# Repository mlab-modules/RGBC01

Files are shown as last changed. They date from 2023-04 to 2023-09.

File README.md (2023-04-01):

<!--- PrjInfo ---> <!--- Please remove this line after manually editing --->
<!--- 00a56be08b96043df9e37d6aff7b6990 --->
<!--- Created:2019-02-18 14:37:02.434774: ---> 
<!--- Author:: ---> 
<!--- AuthorEmail:: ---> 
<!--- Tags:: ---> 
<!--- Ust:: ---> 
<!--- Label --->
<!--- ELabel ---> 
<!--- Name:RGBC01A: --->
# RGBC01A
<!--- LongName --->
## I2C sensor colored light
<!--- ELongName ---> 

<!--- Lead --->
The sensor comprises a sensor red, green, blue and clear colors. Communication takes place via the I2C interface. Circuit includes a power supply for external IR LED. The sensor can be used to measure lighting conditions, or also for detection of the line for the bar and the robot for sensing rotation of automotive wheels.
<!--- ELead ---> 

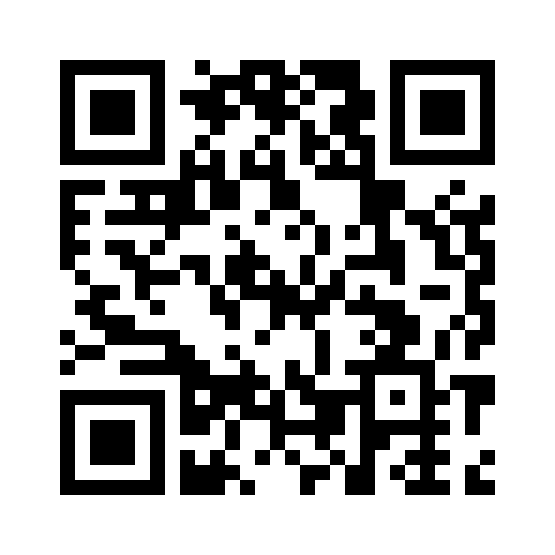
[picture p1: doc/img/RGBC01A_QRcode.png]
RGBC01A
 

<!--- Description --->
<!--- EDescription --->
<!--- Content --->
<!--- EContent --->
<sub><sup> Generated with [MLABweb](https://github.com/MLAB-project/MLABweb). (2019-02-18)</sup></sub>

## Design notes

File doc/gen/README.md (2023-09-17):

# PCB

Board size: 40.13x9.65 mm (1.58x0.38 inches)

- This is the size of the rectangle that contains the board
- Thickness: 1.6 mm (63 mils)
- Material: FR4
- Finish: HAL
- Layers: 2
- Copper thickness: 35 µm

Solder mask: TOP / BOTTOM

- Color: Green

Silk screen: TOP / BOTTOM

- Color: White

# Important sizes

Clearance: 0.2 mm (8 mils)

Track width: 0.4 mm (16 mils)

- By design rules: 0.2 mm (8 mils)

Drill: 0.5 mm (20 mils)

- Vias: 0.5 mm (20 mils) [Design: 0.4 mm (16 mils)]
- Pads: 0.85 mm (33 mils)
- The above values are real drill sizes, they add 0.1 mm (4 mils) to plated holes (PTH)

Via: 0.6/0.4 mm (24/16 mils)

- By design rules: 0.4/0.3 mm (16/12 mils)
- Micro via: yes [0.2/0.1 mm (8/4 mils)]
- Buried/blind via: yes
- Total: 9 (thru: 9 buried/blind: 0 micro: 0)

Outer Annular Ring: 0.05 mm (2 mils)

- By design rules: 0.08 mm (3 mils)

Eurocircuits class: 10B
- Using min drill 0.5 mm for an OAR of 0.05 mm

# General stats

Components count: (SMD/THT)

- Top: 0/7 (THT)
- Bottom: 9/3 (SMD + THT)

Defined tracks:

- 0.2 mm (8 mils)
- 0.3 mm (12 mils)
- 0.4 mm (16 mils)

Used tracks:

- 0.4 mm (16 mils) (90) defined: yes

Defined vias:

Used vias:

- 0.6/0.4 mm (24/16 mils) (Count: 9, Aspect: 2.7 A) defined: no

Holes (excluding vias):

- 0.76 mm (30 mils) (3)
- 0.89 mm (35 mils) (10)
- 3.0 mm (118 mils) (2)

Oval holes:

Drill tools (including vias and computing adjusts and rounding):

- 0.5 mm (20 mils) (9)
- 0.85 mm (33 mils) (3)
- 1.0 mm (39 mils) (10)
- 3.1 mm (122 mils) (2)

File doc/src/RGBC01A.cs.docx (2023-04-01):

I2C snímač barevného světla

Jan Chroust

## Čidlo obsahuje snímač červené, zelené, modré a jasné (clear) barvy. Komunikace probíhá přes I2C rozhraní. Obvod obsahuje i napájení pro externí IR LED. Senzor je možné využít pro měření světelných podmínek, nebo také pro detekci čáry pro čárového robota i pro snímání otáčení pohonných kol.

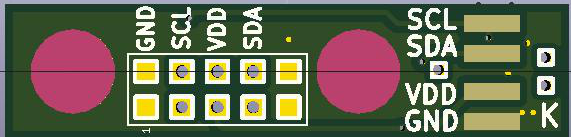
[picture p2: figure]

# 1. Technické parametry

Parametr | Hodnota | Poznámka
Napájecí napětí | 3,3 V
Rozhraní | I2C
I2C adresa | 0x29
Rozměry | 10.13 x 40.13 x 16 mm | Výška nad základní deskou

# 2. Popis konstrukce

Na plošném spoji jsou připraveny vývody pro připojení externí IR LED, pro případ, kdy by nestačila SMD LED umístěna na plošném spoji.

V případě potřeby je možné využít pinu INT, který není na plošném spoji onačen. Je umístěn mezi nápisy SDA a VDD.

Modul byl koncipován tak, že v případě potřeby miniaturizace rozměrů modulu je možné odstřižení plošného spoje hned za prokovem u nápisu GND. Tímto odstřižením se přichází o hřebínek a ochrannou diodu D1.

Adresa modulu je 0x29.

## 2.1. Mechanická konstrukce

Modul obsahuje úchytné šroubky ve všech rozích v rozteči MLAB (10.16mm).

# 3. Osazení a oživení

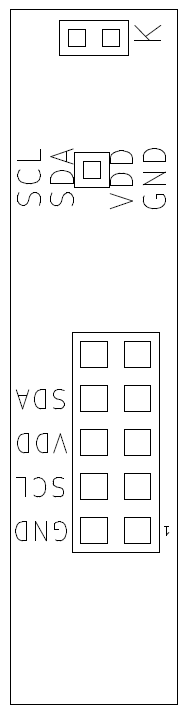
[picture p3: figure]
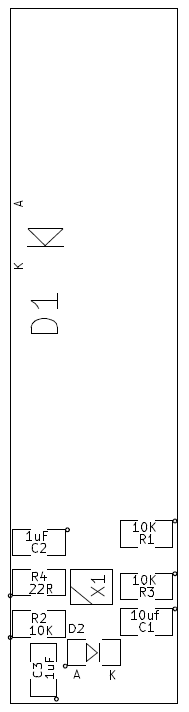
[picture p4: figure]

## 3.1. Osazení

Označení | Typ | Pouzdro | Počet
J3 | CONN1_2 | Straight_2x01 | 1
M1,M2 | HOLE | MountingHole_3mm | 2
X1 | TCS37717 | FN | 1
J1 | JUMP_5X2 | Straight_2x05 | 1
C1 | 10uf | SMD-0805 | 1
C2,C3 | 1uF | SMD-0805 | 2
R1,R3,R2 | 10K | SMD-0805 | 3
R4 | 22R | SMD-0805 | 1
D1 | BZV55C-3,6V | Diode-MiniMELF_Standard | 1
J2 | CONN1_1 | Straight_1x01 | 1
J4,J5,J6,J7 | CONN1_1 | SMD_1x1 | 4
D2 | LL-S170IRC-2A | LED_0805 | 1

RGBC01A / 2016-03-09 / jacho/ http://www.mlab.cz 3 / 3

RGBC01A MLAB

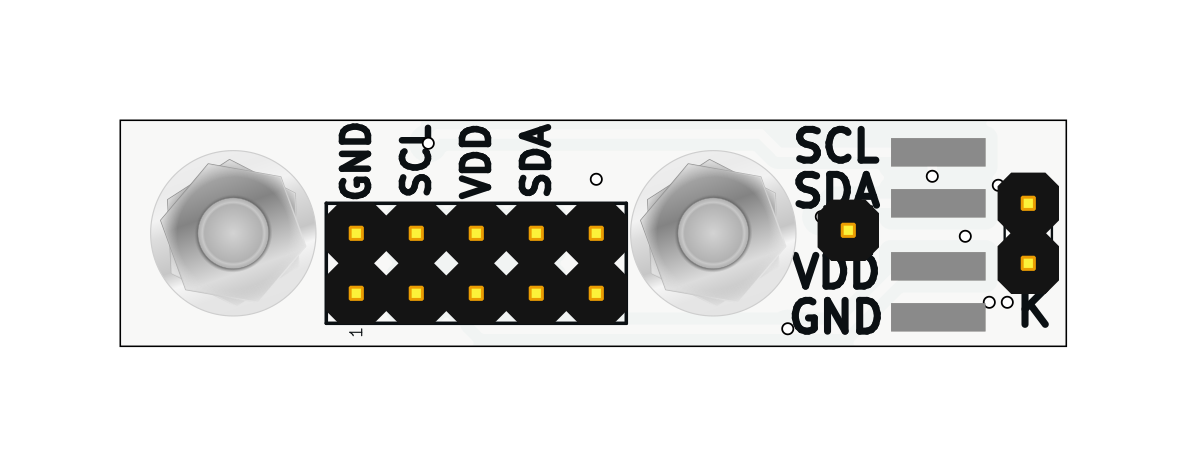
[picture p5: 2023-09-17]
doc/gen/img/RGBC01-top.png

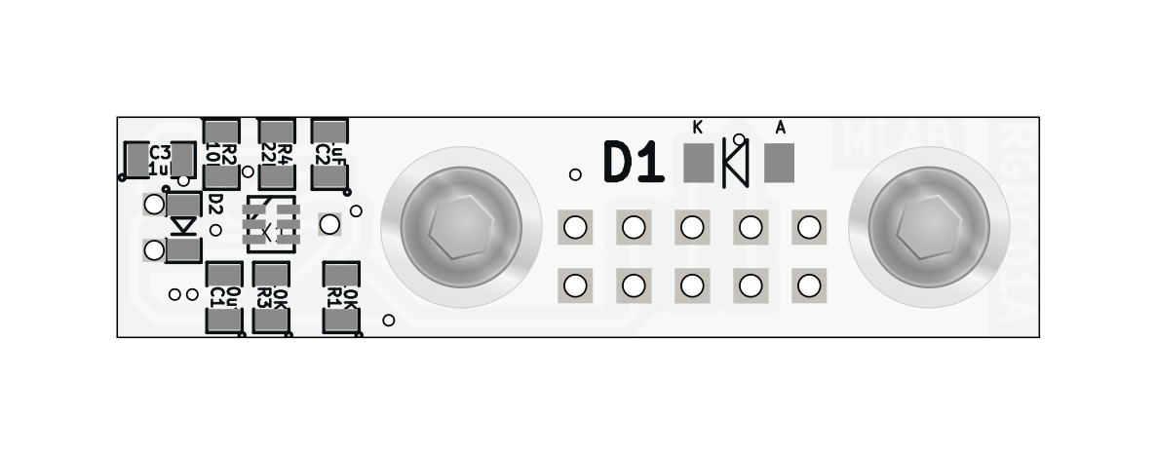
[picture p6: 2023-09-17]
doc/gen/img/RGBC01-bottom.png

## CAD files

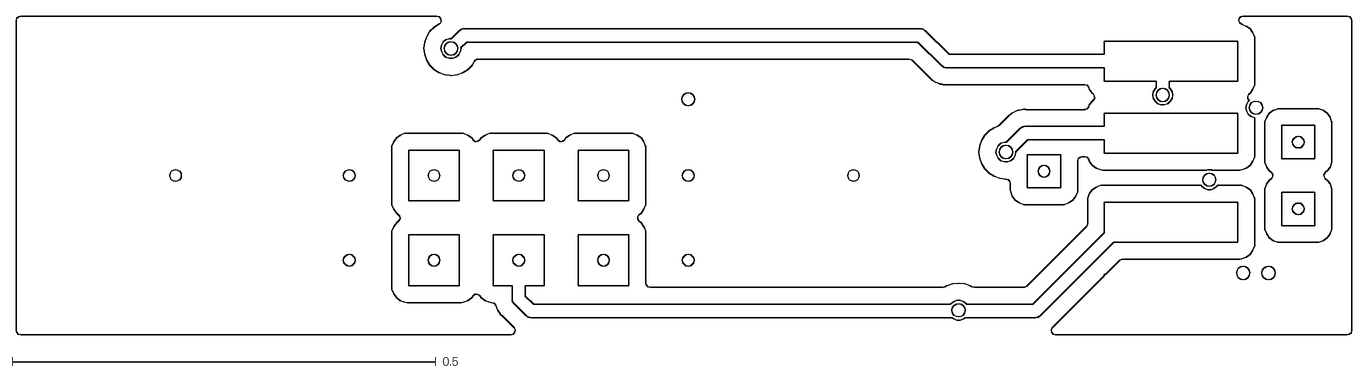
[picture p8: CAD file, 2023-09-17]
doc/gen/dxf/RGBC01-F_Cu.dxf
1.58 x 0.376

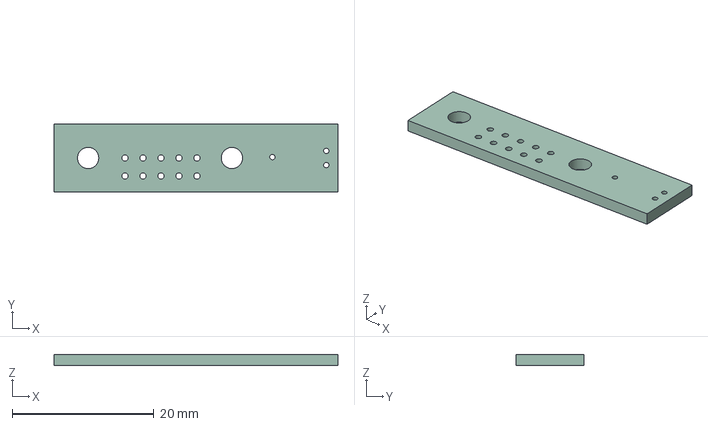
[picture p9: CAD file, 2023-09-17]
doc/gen/RGBC01.step
40.1 x 9.65 x 1.60 mm

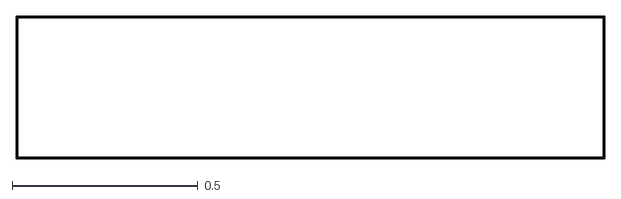
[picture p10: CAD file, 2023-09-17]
doc/gen/dxf/RGBC01-Edge_Cuts.dxf
1.58 x 0.384

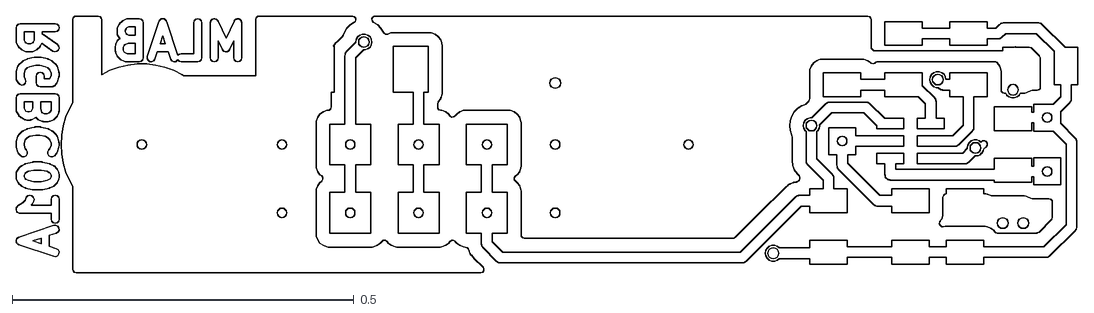
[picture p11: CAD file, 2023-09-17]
doc/gen/dxf/RGBC01-B_Cu.dxf
1.55 x 0.376

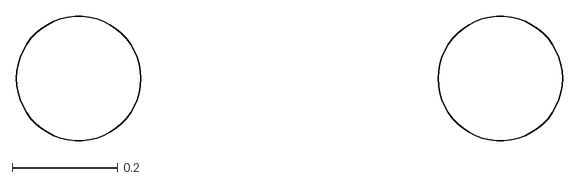
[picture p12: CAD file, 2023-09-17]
doc/gen/dxf/RGBC01-F_Adhesive.dxf
1.04 x 0.236

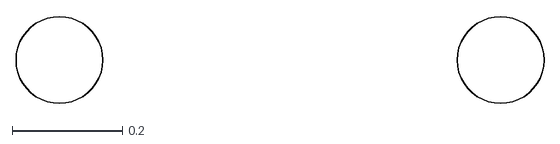
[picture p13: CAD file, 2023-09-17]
doc/gen/dxf/RGBC01-User_Comments.dxf
0.957 x 0.157

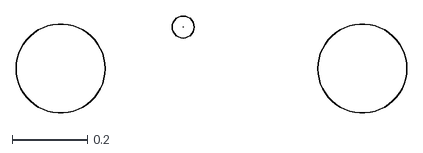
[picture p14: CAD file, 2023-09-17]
doc/gen/dxf/RGBC01-B_Adhesive.dxf
1.04 x 0.257

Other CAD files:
doc/gen/dxf/RGBC01-B_Courtyard.dxf
doc/gen/dxf/RGBC01-User_Eco2.dxf
doc/gen/dxf/RGBC01-User_Drawings.dxf
doc/gen/dxf/RGBC01-Margin.dxf
doc/gen/dxf/RGBC01-User_Eco1.dxf
doc/gen/dxf/RGBC01-F_Fab.dxf
doc/gen/dxf/RGBC01-F_Courtyard.dxf
doc/gen/dxf/RGBC01-B_Fab.dxf
doc/gen/dxf/RGBC01-B_Mask.dxf
doc/gen/dxf/RGBC01-B_Paste.dxf
doc/gen/dxf/RGBC01-B_Silkscreen.dxf
doc/gen/dxf/RGBC01-F_Mask.dxf
doc/gen/dxf/RGBC01-F_Paste.dxf
doc/gen/dxf/RGBC01-F_Silkscreen.dxf

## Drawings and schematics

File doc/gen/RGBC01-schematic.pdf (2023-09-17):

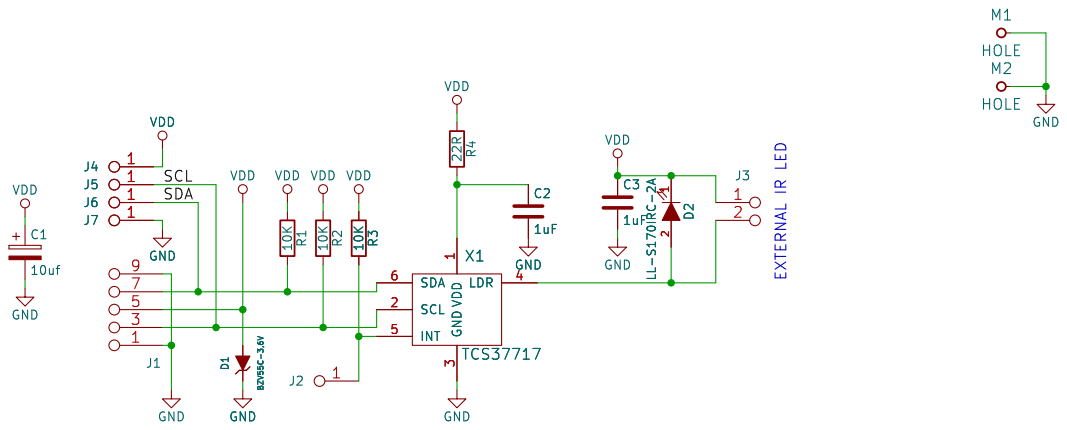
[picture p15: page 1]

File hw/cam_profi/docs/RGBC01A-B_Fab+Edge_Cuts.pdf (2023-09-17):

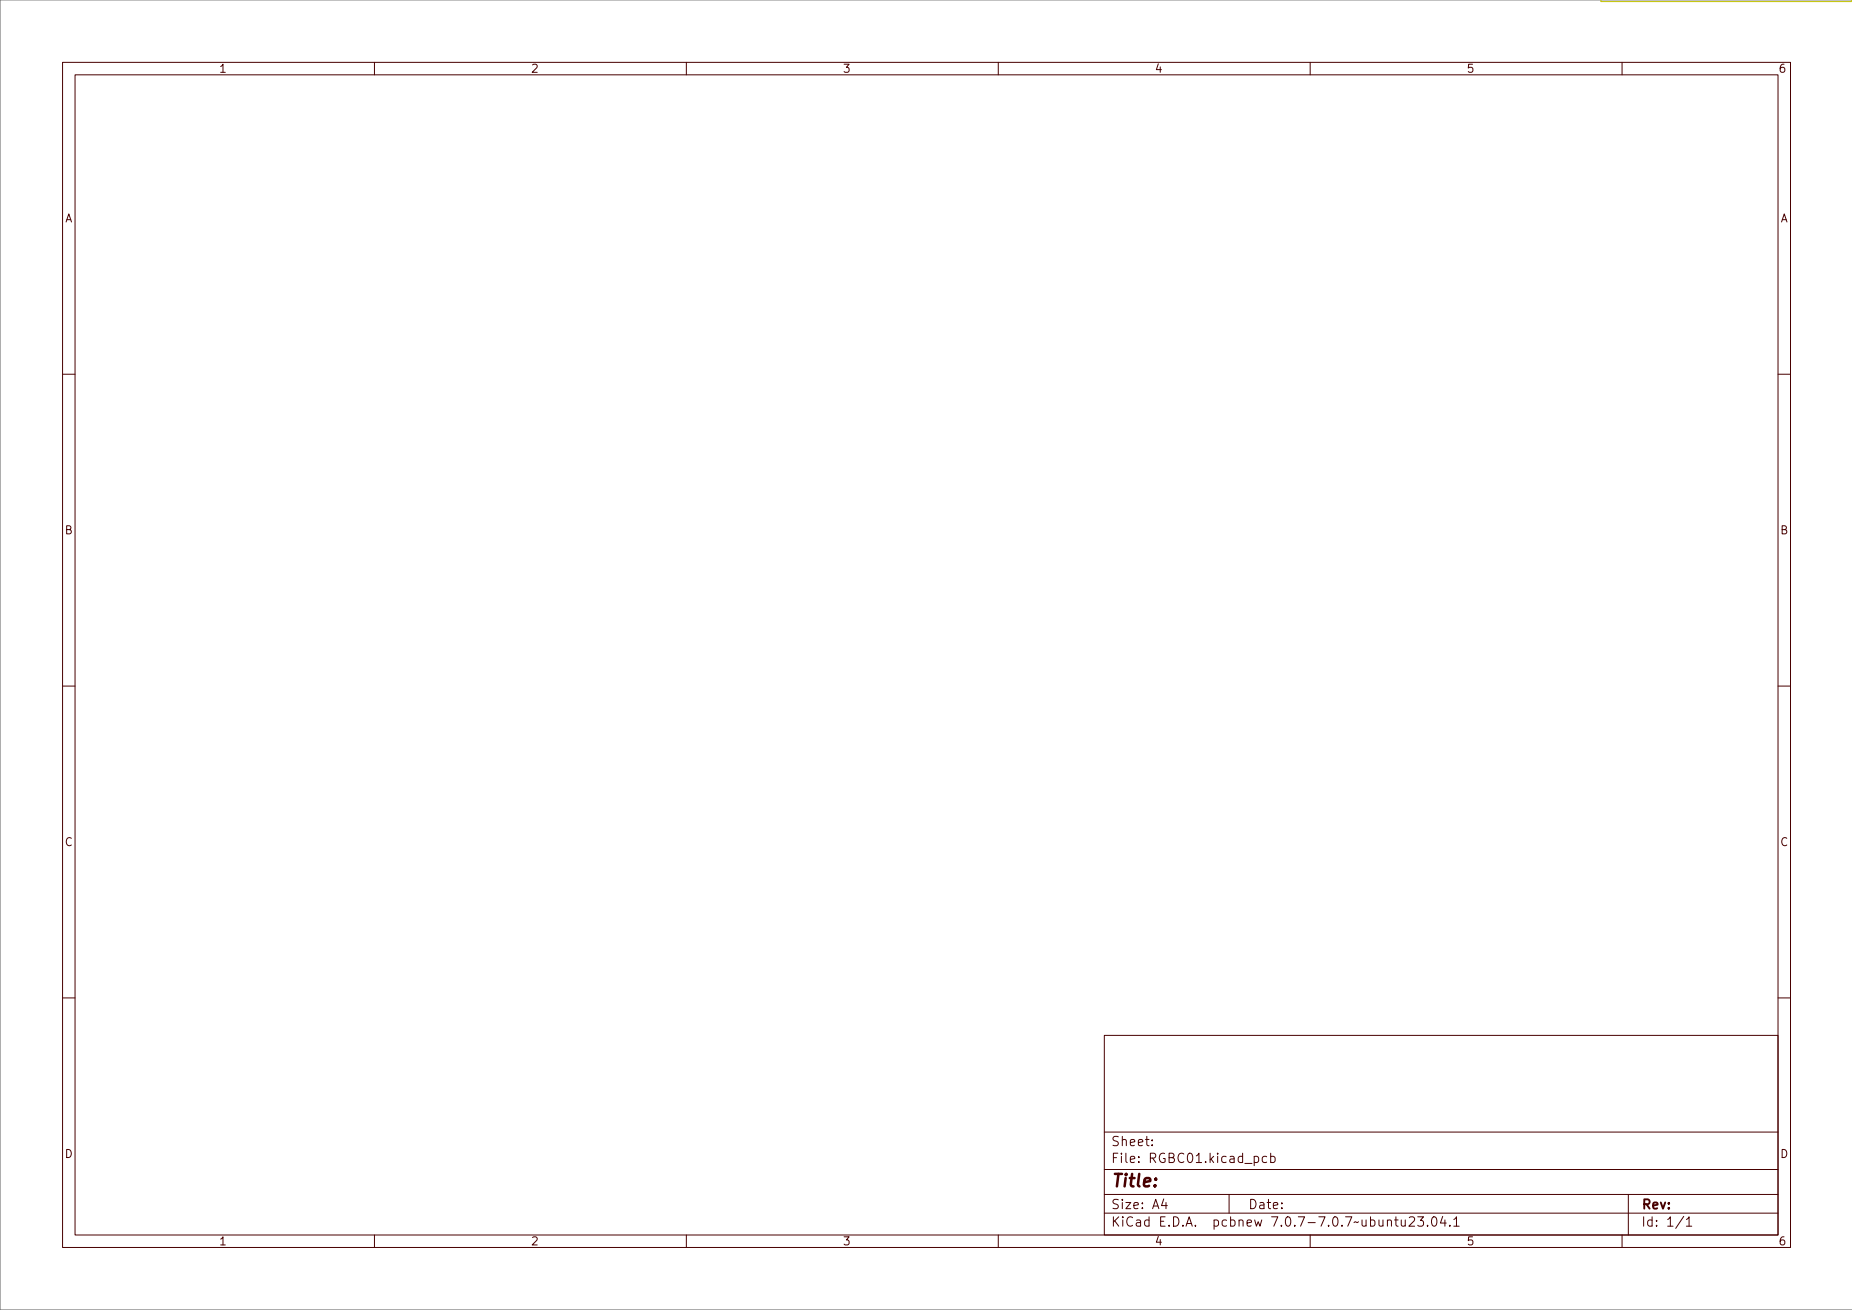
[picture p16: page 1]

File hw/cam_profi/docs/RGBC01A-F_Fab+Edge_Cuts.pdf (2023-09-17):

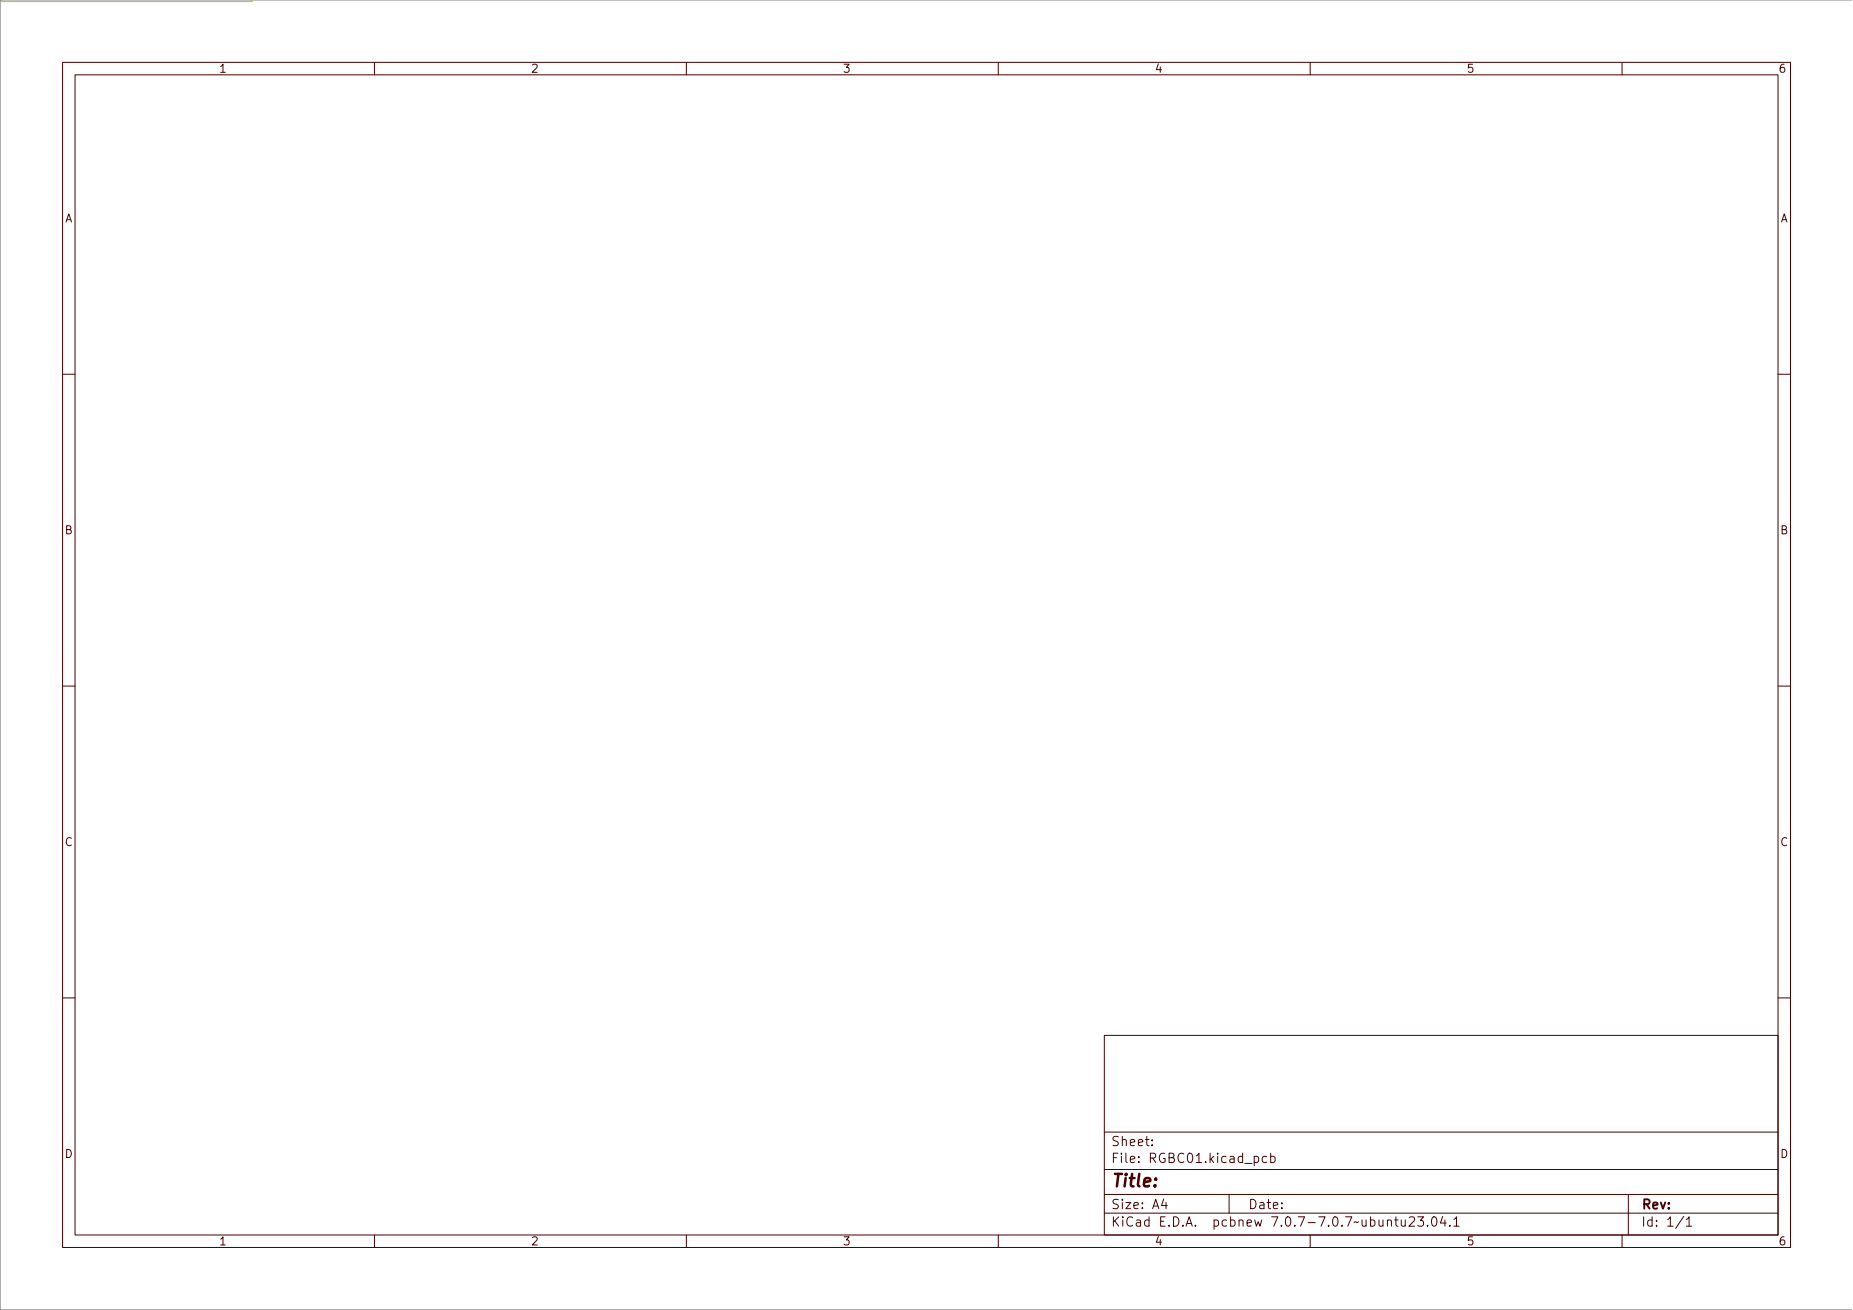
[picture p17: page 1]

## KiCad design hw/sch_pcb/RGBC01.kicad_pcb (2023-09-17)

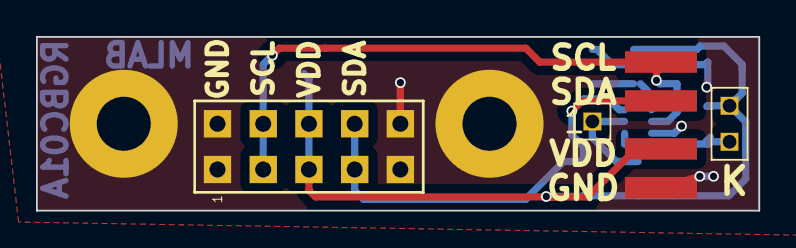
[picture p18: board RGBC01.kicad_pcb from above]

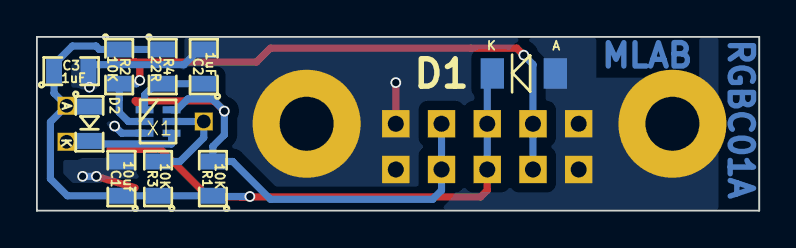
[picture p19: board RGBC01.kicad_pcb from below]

Board: 2 copper layers, 40.1 x 9.7 mm, 19 parts (12 on the bottom side), 7 nets.

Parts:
C1: 10uf; SMD-0805
C2, C3: 1uF; SMD-0805
D1: BZV55C-3,6V; Diode-MiniMELF_Standard
D2: LL-S170IRC-2A; LED_0805
J1: JUMP_5X2; Straight_2x05
J2: CONN1_1; Straight_1x01
J3: CONN1_2; Straight_2x01
J4, J5, J6, J7: CONN1_1; SMD_1x1
M1, M2: HOLE; MountingHole_3mm
R1, R2, R3: 10K; SMD-0805
R4: 22R; SMD-0805
X1: TCS37717; FN

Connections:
/SCL: J1.3, J1.4, J5.1, R2.2, X1.2
/SDA: J1.7, J1.8, J6.1, R1.2, X1.6
GND: C1.2, C2.2, C3.2, D1.1, J1.1, J1.2, J1.9, J1.10, J7.1, M1.1, M2.1, X1.3
unnamed: C2.1, R4.2, X1.1
unnamed: D2.2, J3.2, X1.4
unnamed: J2.1, R3.2, X1.5
VDD: C1.1, C3.1, D1.2, D2.1, J1.5, J1.6, J3.1, J4.1, R1.1, R2.1, R3.1, R4.1

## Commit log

2023-04-01 Adding force option to enable splitting in not fresh copy of Modules repository.
    [RGBC01A.kicad_pcb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]
2023-07-05 automated commit; rename source files to new naming convence
    [RGBC01.kicad_pcb]
2023-09-17 Convert project to KiCAD 7.
    [RGBC01.kicad_pcb, RGBC01.kicad_sch, RGBC01A.sch]
2023-09-17 Update actions products
    [RGBC01-B_Adhesive.dxf, RGBC01-B_Courtyard.dxf, RGBC01-B_Cu.dxf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]
